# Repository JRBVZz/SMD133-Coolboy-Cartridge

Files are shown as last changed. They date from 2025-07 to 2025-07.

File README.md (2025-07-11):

#### COOLBOY - картридж многоигровка для Денди/Famicom

Картридж основан на ASIC **AA6023** в корпусе LQFP-48 с маркировкой **SMD133** и имеет следующие характеристики:
* **PRG ROM**: до 32 МБ
* **CHR RAM**: до 256 КБ
* **PRG RAM**: 8/32 КБ, FRAM или SRAM

Проект создан в [**KiCad 9**](https://www.kicad.org/).

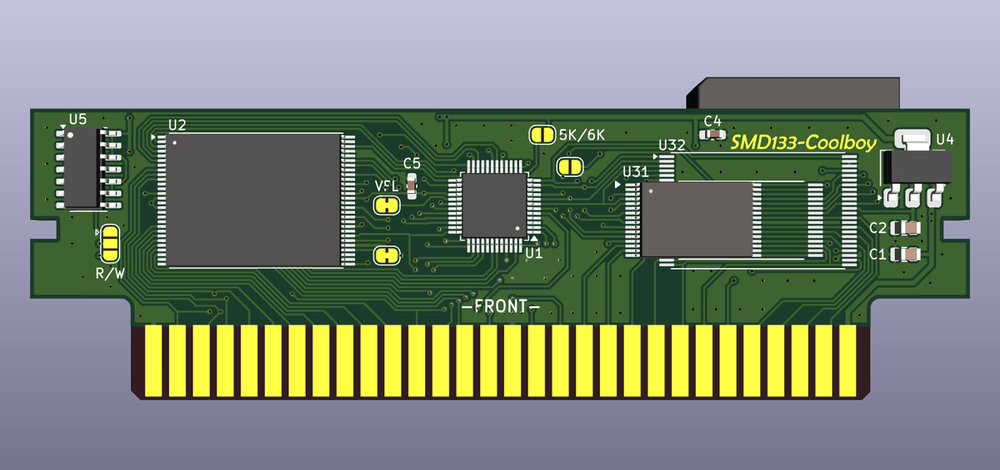
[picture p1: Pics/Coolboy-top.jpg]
3D Top


#### Параметры для изготовления PCB
* 2 слоя
* Толщина PCB: 1.2 мм
* Рекомендуется ENIG покрытие контактов краевого разъема

#### Схема
[Schematic PDF](Pics/Coolboy-schematic.pdf)

#### Интерактивный BOM
[BoM](BOM/Coolboy-iBOM.html) (для корректного просмотра нужно скачать raw файл)

#### Прошивка
Для прошивки картриджа без пайки, перемычка должна соединять среднюю и нижнюю площадки у джампера "R/W". Картридж можно перепрошить с помощью [Famicom/NES Dumper/Writer](https://github.com/ClusterM/famicom-dumper-writer), собрать ROM-файл можно в [COOLBOY Multirom Builder](https://github.com/ClusterM/coolboy-multirom-builder). Спасибо Алексею Кластеру за эти отличные инструменты.

PS Герберы не выкладываю специально - это мой небольшой вклад в популяризацию KiCad :smile:

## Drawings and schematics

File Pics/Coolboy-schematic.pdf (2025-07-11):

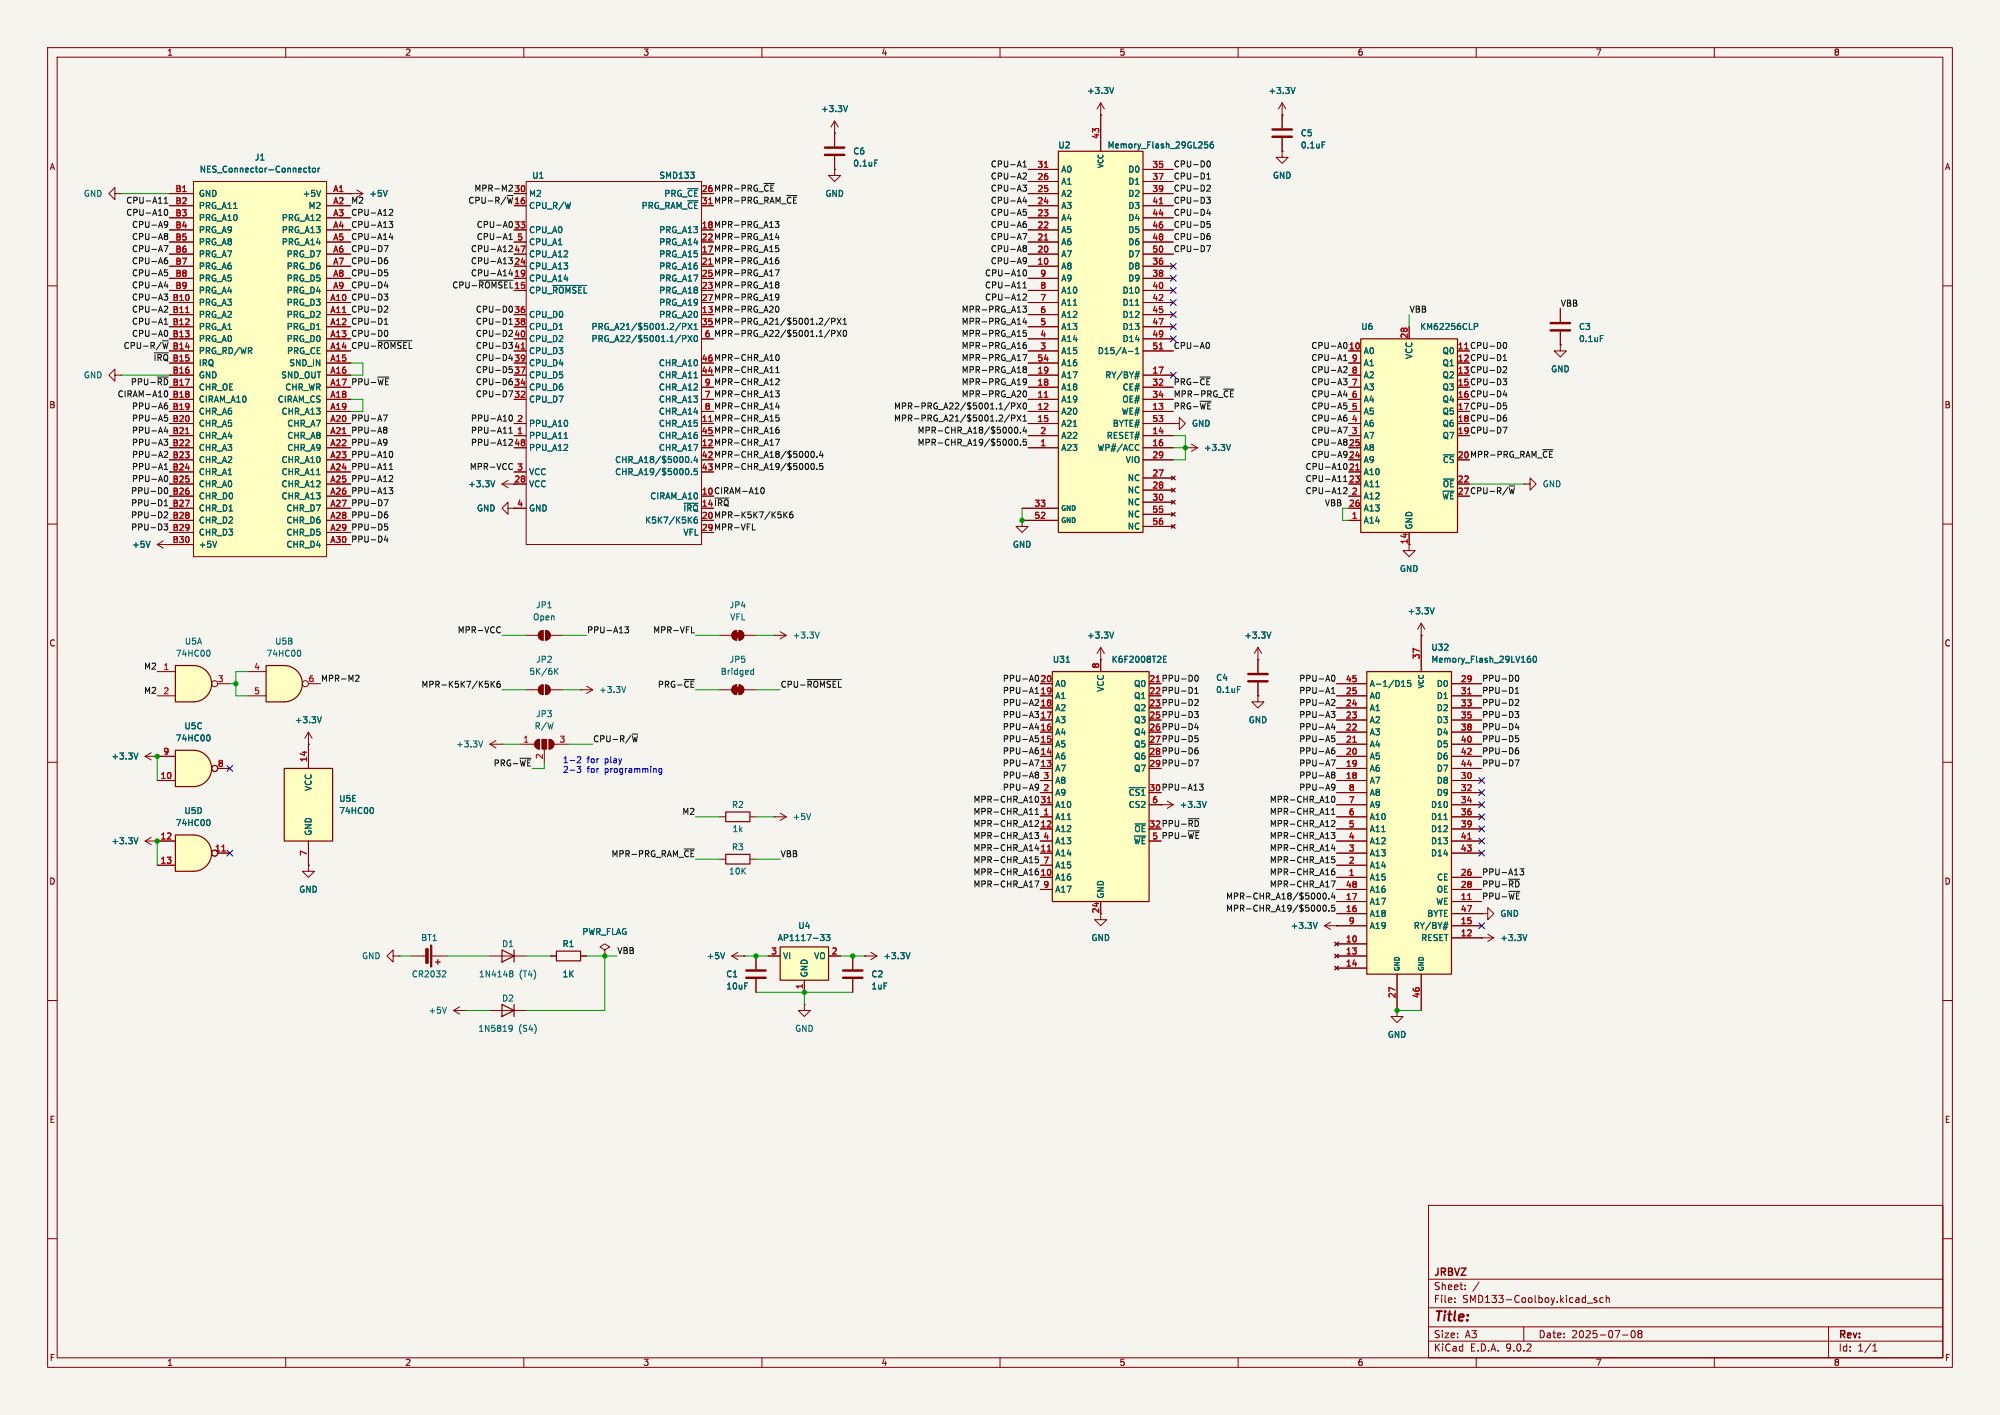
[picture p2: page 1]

Id: 1/1 Title: File: SMD133-Coolboy.kicad_sch Sheet: / JRBVZ VCC
0.1uF GND

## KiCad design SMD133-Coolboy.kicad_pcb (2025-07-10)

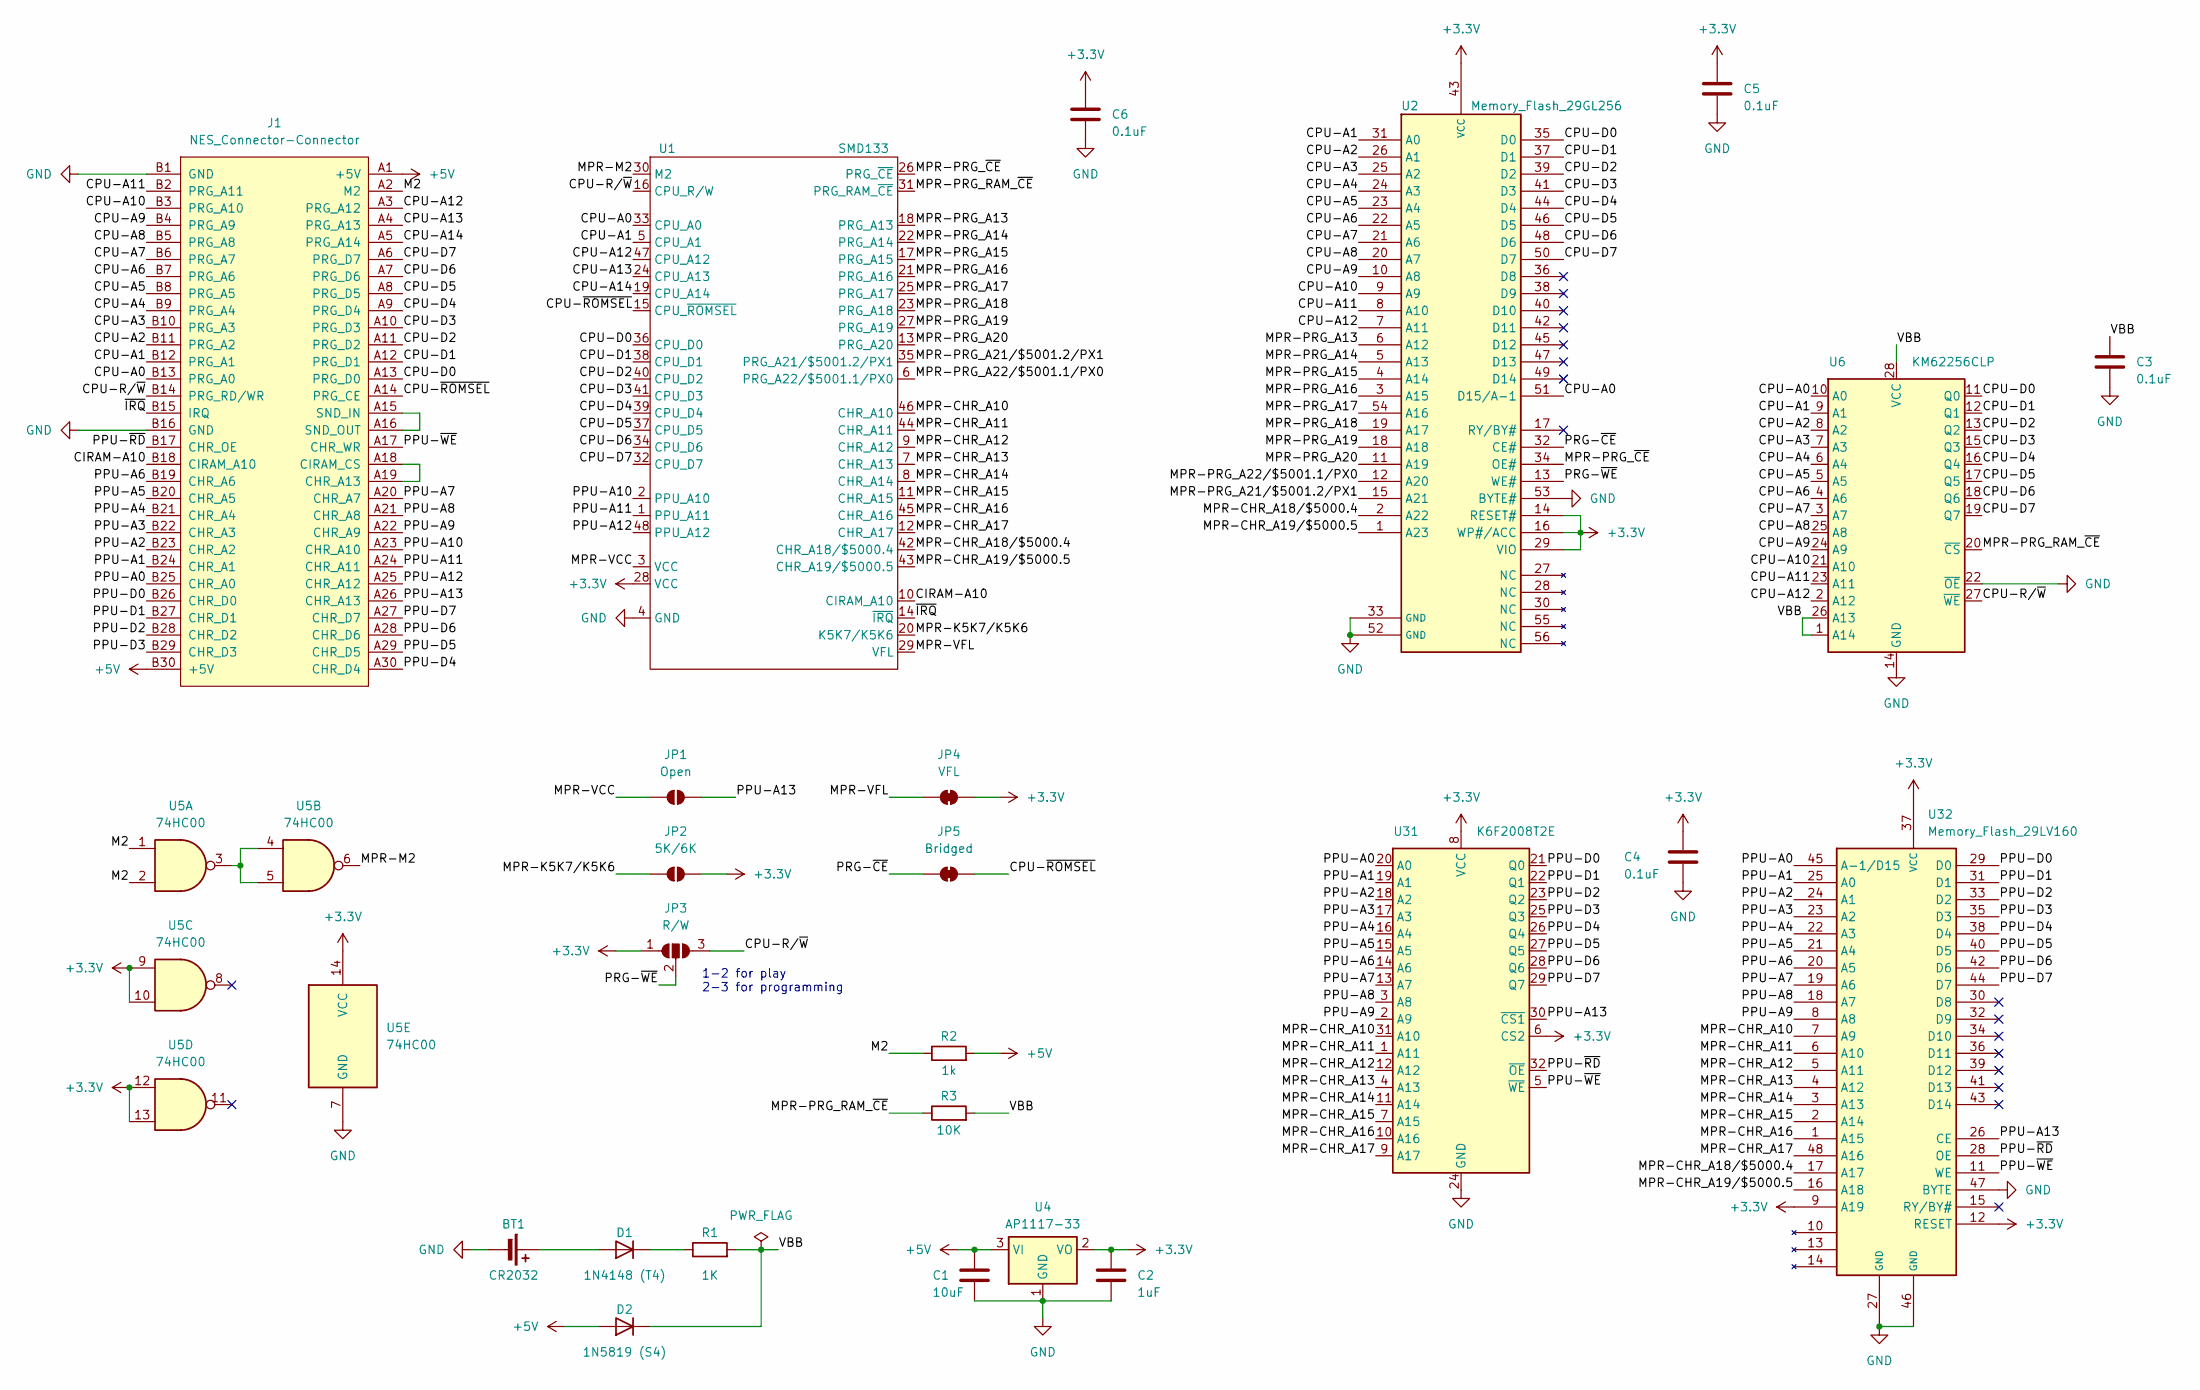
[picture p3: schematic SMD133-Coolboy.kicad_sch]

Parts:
BT1: CR2032; BatteryHolder_2032
C1: 10uF; C_0805_2012Metric
C2: 1uF; C_0805_2012Metric
C3, C4, C5, C6: 0.1uF; C_0603_1608Metric_Pad1.08x0.95mm_HandSolder
D1: 1N4148 (T4); D_SOD-123
D2: 1N5819 (S4); D_SOD-123
J1: NES_Connector-Connector; NES_Connector_L
JP1: Open; SolderJumper-2_P1.3mm_Open_RoundedPad1.0x1.5mm
JP2: 5K/6K; SolderJumper-2_P1.3mm_Open_RoundedPad1.0x1.5mm
JP3: R/W; SolderJumper-3_P1.3mm_Open_RoundedPad1.0x1.5mm
JP4: VFL; SolderJumper-2_P1.3mm_Bridged_RoundedPad1.0x1.5mm
JP5: Bridged; SolderJumper-2_P1.3mm_Bridged_RoundedPad1.0x1.5mm
R1: 1K; R_0805_2012Metric
R2: 1k; R_0805_2012Metric
R3: 10K; R_0805_2012Metric
U1: SMD133; LQFP-48_7x7mm_P0.5mm
U2: Memory_Flash_29GL256; TSOP-I-56_18.4x14mm_P0.5mm
U4: AP1117-33; SOT-89-223
U5: 74HC00; SO-14_3.9x8.65mm_P1.27mm
U6: KM62256CLP; SOP-28
U31: K6F2008T2E; TSOP-I-32_11.8-18.4x8mm_P0.5mm
U32: Memory_Flash_29LV160; TSOP-I-48_18.4x12mm_P0.5mm

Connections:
+3.3V: C2.1, C4.1, C5.1, C6.1, JP2.2 (B), JP3.1 (A), JP4.2 (B), U1.28 (VCC), U2.14 (RESET#), U2.16 (WP#/ACC), U2.29 (VIO), U2.43 (VCC), U4.2 (VO), U5.9, U5.10, U5.12, U5.13, U5.14 (VCC), U31.6 (CS2), U31.8 (VCC), U32.9 (A19), U32.12 (RESET), U32.37 (VCC)
+5V: C1.1, D2.2 (A), J1.A1 (+5V), J1.B30 (+5V), R2.2, U4.3 (VI)
/CIRAM-A10: J1.B18 (CIRAM_A10), U1.10 (CIRAM_A10)
/CPU-A0: J1.B13 (PRG_A0), U1.33 (CPU_A0), U2.51 (D15/A-1), U6.10 (A0)
/CPU-A1: J1.B12 (PRG_A1), U1.5 (CPU_A1), U2.31 (A0), U6.9 (A1)
/CPU-A2: J1.B11 (PRG_A2), U2.26 (A1), U6.8 (A2)
/CPU-A3: J1.B10 (PRG_A3), U2.25 (A2), U6.7 (A3)
/CPU-A4: J1.B9 (PRG_A4), U2.24 (A3), U6.6 (A4)
/CPU-A5: J1.B8 (PRG_A5), U2.23 (A4), U6.5 (A5)
/CPU-A6: J1.B7 (PRG_A6), U2.22 (A5), U6.4 (A6)
/CPU-A7: J1.B6 (PRG_A7), U2.21 (A6), U6.3 (A7)
/CPU-A8: J1.B5 (PRG_A8), U2.20 (A7), U6.25 (A8)
/CPU-A9: J1.B4 (PRG_A9), U2.10 (A8), U6.24 (A9)
/CPU-A10: J1.B3 (PRG_A10), U2.9 (A9), U6.21 (A10)
/CPU-A11: J1.B2 (PRG_A11), U2.8 (A10), U6.23 (A11)
/CPU-A12: J1.A3 (PRG_A12), U1.47 (CPU_A12), U2.7 (A11), U6.2 (A12)
/CPU-A13: J1.A4 (PRG_A13), U1.24 (CPU_A13)
/CPU-A14: J1.A5 (PRG_A14), U1.19 (CPU_A14)
/CPU-D0: J1.A13 (PRG_D0), U1.36 (CPU_D0), U2.35 (D0), U6.11 (Q0)
/CPU-D1: J1.A12 (PRG_D1), U1.38 (CPU_D1), U2.37 (D1), U6.12 (Q1)
/CPU-D2: J1.A11 (PRG_D2), U1.40 (CPU_D2), U2.39 (D2), U6.13 (Q2)
/CPU-D3: J1.A10 (PRG_D3), U1.41 (CPU_D3), U2.41 (D3), U6.15 (Q3)
/CPU-D4: J1.A9 (PRG_D4), U1.39 (CPU_D4), U2.44 (D4), U6.16 (Q4)
/CPU-D5: J1.A8 (PRG_D5), U1.37 (CPU_D5), U2.46 (D5), U6.17 (Q5)
/CPU-D6: J1.A7 (PRG_D6), U1.34 (CPU_D6), U2.48 (D6), U6.18 (Q6)
/CPU-D7: J1.A6 (PRG_D7), U1.32 (CPU_D7), U2.50 (D7), U6.19 (Q7)
/CPU-R/~W: J1.B14 (PRG_RD/WR), JP3.3 (B), U1.16 (CPU_R/W), U6.27 (~WE)
/CPU-~ROMSEL: J1.A14 (PRG_CE), JP5.2 (B), U1.15 (CPU_~ROMSEL)
/M2: J1.A2 (M2), R2.1, U5.1, U5.2
/MPR-CHR_A10: U1.46 (CHR_A10), U31.31 (A10), U32.7 (A9)
/MPR-CHR_A11: U1.44 (CHR_A11), U31.1 (A11), U32.6 (A10)
/MPR-CHR_A12: U1.9 (CHR_A12), U31.12 (A12), U32.5 (A11)
/MPR-CHR_A13: U1.7 (CHR_A13), U31.4 (A13), U32.4 (A12)
/MPR-CHR_A14: U1.8 (CHR_A14), U31.11 (A14), U32.3 (A13)
/MPR-CHR_A15: U1.11 (CHR_A15), U31.7 (A15), U32.2 (A14)
/MPR-CHR_A16: U1.45 (CHR_A16), U31.10 (A16), U32.1 (A15)
/MPR-CHR_A17: U1.12 (CHR_A17), U31.9 (A17), U32.48 (A16)
/MPR-CHR_A18/$5000.4: U1.42 (CHR_A18/$5000.4), U2.2 (A22), U32.17 (A17)
/MPR-CHR_A19/$5000.5: U1.43 (CHR_A19/$5000.5), U2.1 (A23), U32.16 (A18)
/MPR-K5K7/K5K6: JP2.1 (A), U1.20 (K5K7/K5K6)
/MPR-M2: U1.30 (M2), U5.6
/MPR-PRG_A13: U1.18 (PRG_A13), U2.6 (A12)
/MPR-PRG_A14: U1.22 (PRG_A14), U2.5 (A13)
/MPR-PRG_A15: U1.17 (PRG_A15), U2.4 (A14)
/MPR-PRG_A16: U1.21 (PRG_A16), U2.3 (A15)
/MPR-PRG_A17: U1.25 (PRG_A17), U2.54 (A16)
/MPR-PRG_A18: U1.23 (PRG_A18), U2.19 (A17)
/MPR-PRG_A19: U1.27 (PRG_A19), U2.18 (A18)
/MPR-PRG_A20: U1.13 (PRG_A20), U2.11 (A19)
/MPR-PRG_A21/$5001.2/PX1: U1.35 (PRG_A21/$5001.2/PX1), U2.15 (A21)
/MPR-PRG_A22/$5001.1/PX0: U1.6 (PRG_A22/$5001.1/PX0), U2.12 (A20)
/MPR-PRG_RAM_~CE: R3.1, U1.31 (PRG_RAM_~CE), U6.20 (~CS)
/MPR-PRG_~CE: U1.26 (PRG_~CE), U2.34 (OE#)
/MPR-VCC: JP1.1 (A), U1.3 (VCC)
/MPR-VFL: JP4.1 (A), U1.29 (VFL)
/PPU-A0: J1.B25 (CHR_A0), U31.20 (A0), U32.45 (A-1/D15)
/PPU-A1: J1.B24 (CHR_A1), U31.19 (A1), U32.25 (A0)
/PPU-A2: J1.B23 (CHR_A2), U31.18 (A2), U32.24 (A1)
/PPU-A3: J1.B22 (CHR_A3), U31.17 (A3), U32.23 (A2)
/PPU-A4: J1.B21 (CHR_A4), U31.16 (A4), U32.22 (A3)
/PPU-A5: J1.B20 (CHR_A5), U31.15 (A5), U32.21 (A4)
/PPU-A6: J1.B19 (CHR_A6), U31.14 (A6), U32.20 (A5)
/PPU-A7: J1.A20 (CHR_A7), U31.13 (A7), U32.19 (A6)
/PPU-A8: J1.A21 (CHR_A8), U31.3 (A8), U32.18 (A7)
/PPU-A9: J1.A22 (CHR_A9), U31.2 (A9), U32.8 (A8)
/PPU-A10: J1.A23 (CHR_A10), U1.2 (PPU_A10)
/PPU-A11: J1.A24 (CHR_A11), U1.1 (PPU_A11)
/PPU-A12: J1.A25 (CHR_A12), U1.48 (PPU_A12)
/PPU-A13: J1.A26 (CHR_A13), JP1.2 (B), U31.30 (~CS1), U32.26 (CE)
/PPU-D0: J1.B26 (CHR_D0), U31.21 (Q0), U32.29 (D0)
/PPU-D1: J1.B27 (CHR_D1), U31.22 (Q1), U32.31 (D1)
/PPU-D2: J1.B28 (CHR_D2), U31.23 (Q2), U32.33 (D2)
/PPU-D3: J1.B29 (CHR_D3), U31.25 (Q3), U32.35 (D3)
/PPU-D4: J1.A30 (CHR_D4), U31.26 (Q4), U32.38 (D4)
/PPU-D5: J1.A29 (CHR_D5), U31.27 (Q5), U32.40 (D5)
/PPU-D6: J1.A28 (CHR_D6), U31.28 (Q6), U32.42 (D6)
/PPU-D7: J1.A27 (CHR_D7), U31.29 (Q7), U32.44 (D7)
/PPU-~RD: J1.B17 (CHR_OE), U31.32 (~OE), U32.28 (OE)
/PPU-~WE: J1.A17 (CHR_WR), U31.5 (~WE), U32.11 (WE)
/PRG-~CE: JP5.1 (A), U2.32 (CE#)
/PRG-~WE: JP3.2 (C), U2.13 (WE#)
/VBB: C3.1, D2.1 (K), R1.2, R3.2, U6.1 (A14), U6.26 (A13), U6.28 (VCC)
/~IRQ: J1.B15 (IRQ), U1.14 (~IRQ)
GND: BT1.2 (-), C1.2, C2.2, C3.2, C4.2, C5.2, C6.2, J1.B1 (GND), J1.B16 (GND), U1.4 (GND), U2.33 (GND), U2.52 (GND), U2.53 (BYTE#), U4.1 (GND), U5.7 (GND), U6.14 (GND), U6.22 (~OE), U31.24 (GND), U32.27 (GND), U32.46 (GND), U32.47 (BYTE)
unnamed: BT1.1 (+), D1.2 (A)
unnamed: D1.1 (K), R1.1
unnamed: J1.A18 (CIRAM_CS), J1.A19 (CHR_A13)
unnamed: J1.A15 (SND_IN), J1.A16 (SND_OUT)
unnamed: U5.3, U5.4, U5.5

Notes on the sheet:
1-2 for play 2-3 for programming

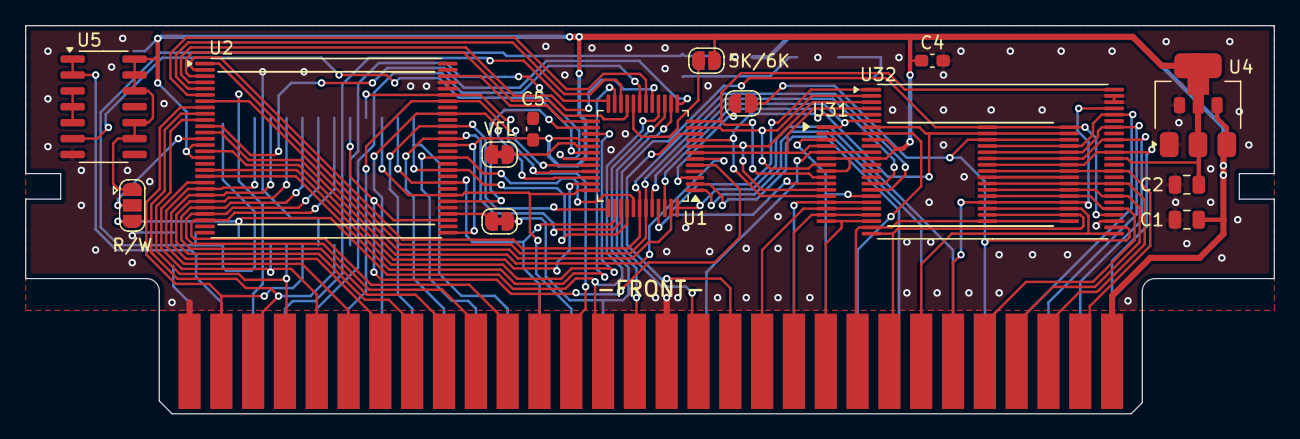
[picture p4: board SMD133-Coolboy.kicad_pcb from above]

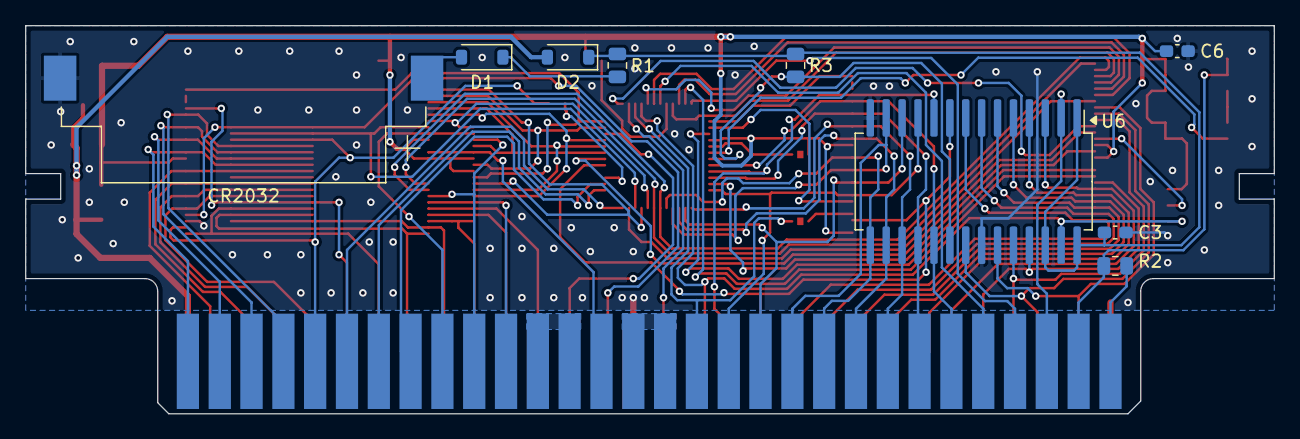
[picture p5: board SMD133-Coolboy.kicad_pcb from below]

Board: 2 copper layers, 99.7 x 31.0 mm, 25 parts (9 on the bottom side), 89 nets.

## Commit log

2025-07-10 1st Commit
    [SMD133-Coolboy.kicad_pcb, SMD133-Coolboy.kicad_sch]
2025-07-11 Add Schematic
2025-07-11 Add BOM
